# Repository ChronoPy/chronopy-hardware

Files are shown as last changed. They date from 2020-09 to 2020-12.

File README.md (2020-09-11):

# ChronoPy - Open Hardware, hacker freindly, wrist watch based on the OHS2020 badge
* [Hackaday.io project page](https://hackaday.io/project/168483-open-hardware-summit-2020-badge)
* [OHS 2020 website](http://2020.oshwa.org/)

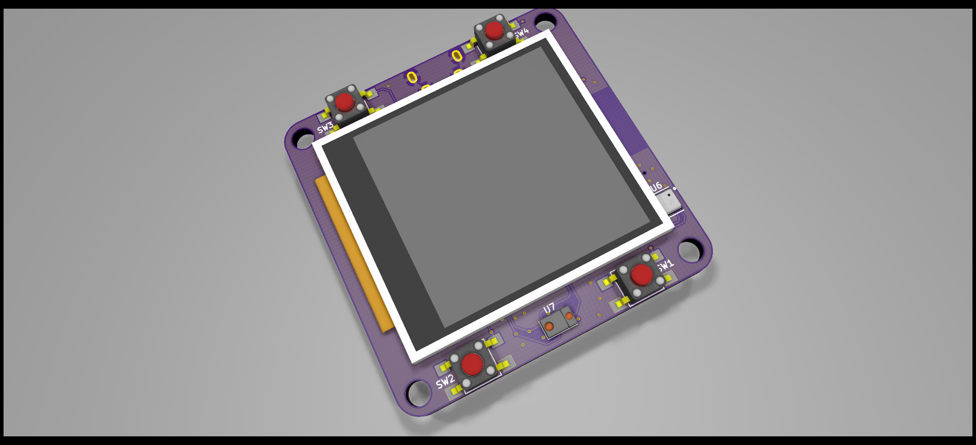
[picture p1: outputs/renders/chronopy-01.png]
Badge top

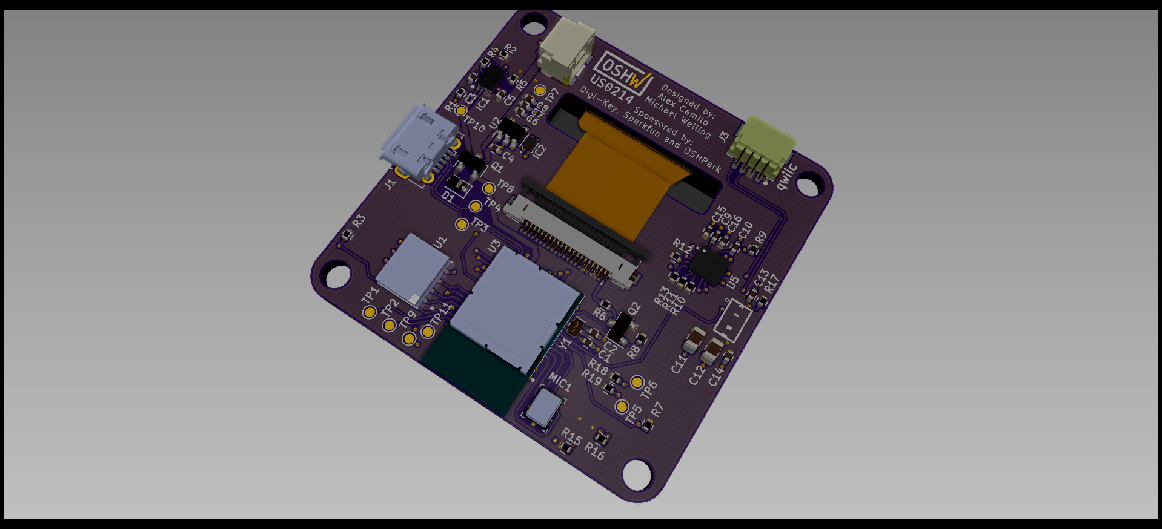
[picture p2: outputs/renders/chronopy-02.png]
Badge bot


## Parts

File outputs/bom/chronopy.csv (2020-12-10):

Reference | Quantity | Value | Footprint | Datasheet | Field4 | Field5 | Field6 | Field7 | Field8 | Description | Height | Manufacturer_Name | Manufacturer_Part_Number | Mouser Part Number | Mouser Price/Stock
C1 C2 | 2 | 18pF | ChronoPy-PCB:C_0402 | ~
C11 C12 | 2 | 10uF | ChronoPy-PCB:C_0805_2012Metric | ~
C18 | 1 | 220nF | ChronoPy-PCB:C_0402 | ~
C19 | 1 | 1uF | ChronoPy-PCB:C_0402 | ~
C15 C3 C4 C5 C6 C7 | 6 | 10uF | ChronoPy-PCB:C_0402 | ~
C10 C13 C14 C16 C17 C8 | 6 | 0.1uF | ChronoPy-PCB:C_0402 | ~
C9 | 1 | 10nF | ChronoPy-PCB:C_0402 | ~
D1 D2 | 2 | D | ChronoPy-PCB:D_SOD-323 | ~
IC1 | 1 | MCP73831T-2ACI_MC | ChronoPy-PCB:SON50P300X200X100-9N-D | https://componentsearchengine.com/Datasheets/1/MCP73831T-2ACI_MC.pdf |  |  |  |  |  | MICROCHIP - MCP73831T-2ACI/MC - BATTERY CHARGER, LI-ION/POL, 0.5A, DFN-8 | 1 | Microchip | MCP73831T-2ACI/MC | 579-MCP73831T-2ACIMC | https://www.mouser.com/Search/Refine.aspx?Keyword=579-MCP73831T-2ACIMC
IC2 | 1 | S-1000C32-I4T1U_S-1000C32-I4T1U | SNT-4A | http://datasheet.sii-ic.com/en/voltage_detector/S1000_E.pdf |  |  |  |  |  | ULTRA-SMALL PACKAGE HIGH-PRECISION VOLTAGE DETECTOR |  | SII Semiconductor | S-1000C32-I4T1U | 628-S-1000C32-I4T1U | http://www.mouser.com/Search/ProductDetail.aspx?qs=h6RIvS%252bzmlf9OAVfz2pa8w%3d%3d
J1 | 1 | USB_B_Micro | ChronoPy-PCB:USB_Micro-B_Molex-105017-0001 | ~
J2 | 1 | SM02B-SRSS-TB | ChronoPy-PCB:SM02B-SRSS-TB | 0.23 USD | JST | None | Good | SH Series 2 Position 1 mm Pitch Surface Mount Side Entry Shrouded Header | SM02B-SRSS-TB_LF__SN_
J3 | 1 | Conn_01x04_Shielded | ChronoPy-PCB:JST_SM04B-SRSS-TB(LF)(SN) | ~
J4 | 1 | Conn_01x13_MountingPin | ChronoPy-PCB:Hirose_FH26W-13S-0.3SHW_2Rows-13Pins-1MP_P0.60mm | ~
J5 | 1 | Conn_01x06_MountingPin | ChronoPy-PCB:Hirose_FH19C-6S-0.5SH_1x06-1MP_P0.50mm | ~
J6 | 1 | Conn_02x05_Odd_Even | Connector_PinHeader_1.27mm:PinHeader_2x05_P1.27mm_Horizontal | ~
J7 | 1 | TC2030-CTX | ChronoPy-PCB:TC2030-IDC-NL
M1 | 1 | Z43FC1B5640007L | ChronoPy-PCB:Z43FC1B5640007L | ~
MK1 | 1 | IM69D120 | Sensor_Audio:Infineon_PG-LLGA-5-1 | https://www.infineon.com/dgdl/Infineon-IM69D120-DS-v01_00-EN.pdf?fileId=5546d462602a9dc801607a0e41a01a2b
Q1 Q2 Q3 | 3 | AO3401A | ChronoPy-PCB:SOT-23 | http://www.aosmd.com/pdfs/datasheet/AO3401A.pdf
R14 | 1 | 800k | ChronoPy-PCB:R_0402 | ~
R17 | 1 | 22 | ChronoPy-PCB:R_0402 | ~
R20 | 1 | 2m | ChronoPy-PCB:R_0402 | ~
R21 R22 | 2 | 1k | ChronoPy-PCB:R_0402 | ~
R23 | 1 | 10m 1% | Resistor_SMD:R_0603_1608Metric | ~
R1 R18 R19 R4 | 4 | 10k | ChronoPy-PCB:R_0402 | ~
R10 R11 R12 R13 R15 R16 R2 R24 R3 R5 R7 R8 R9 | 13 | 100k | ChronoPy-PCB:R_0402 | ~
R6 | 1 | 33 | ChronoPy-PCB:R_0402 | ~
SW1 SW2 SW3 SW4 | 4 | SW_DIP_x01 | ChronoPy-PCB:SW_TL3340AF160QG | ~
TP10 TP12 TP3 TP4 TP5 TP6 TP7 TP8 TP9 | 9 | TestPoint | ChronoPy-PCB:Test_Point_Pad_d1.0mm | ~
U1 | 1 | W25Q32JVZPIQ | ChronoPy-PCB:SON127P600X500X80-9N | http://www.winbond.com/resource-files/w25q32jv%20revg%2003272018%20plus.pdf
U2 | 1 | AP2112K-3.3V | ChronoPy-PCB:SOT-23-5 | http://www.ti.com/lit/ds/symlink/lp2985.pdf
U3 | 1 | BMD-340-A-R | ChronoPy-PCB:RIGADO_BMD-340-A-R | U-Blox America | Module Rigado | Bluetooth Low Energy 5.0 Module | None | BMD-340-A-R | Unavailable
U4 | 1 | STC3115IJT | ChronoPy-PCB:CSP-10
U5 | 1 | LSM9DS1 | ChronoPy-PCB:PQFN24P43_350X300X102L35X23N | STMicroelectronics | TFLGA-24 STMicroelectronics | iNEMO inertial module: 3D accelerometer, 3D gyroscope, 3D magnetometer | None | LSM9DS1 | Unavailable
U6 | 1 | BME680 | ChronoPy-PCB:PSON80P300X300X100-8N | Bosch Sensortec | LGA-8 Bosch Tools | Integrated Environmental Unit | None | BME680 | Unavailable
U7 | 1 | APDS-9960 | ChronoPy-PCB:APDS-9960
Y1 | 1 | 32.768 | ChronoPy-PCB:Crystal_SMD_MicroCrystal_CM9V-T1A-2pin_1.6x1.0mm | https://www.mouser.com/datasheet/2/530/CM9V-T1A-1023054.pdf

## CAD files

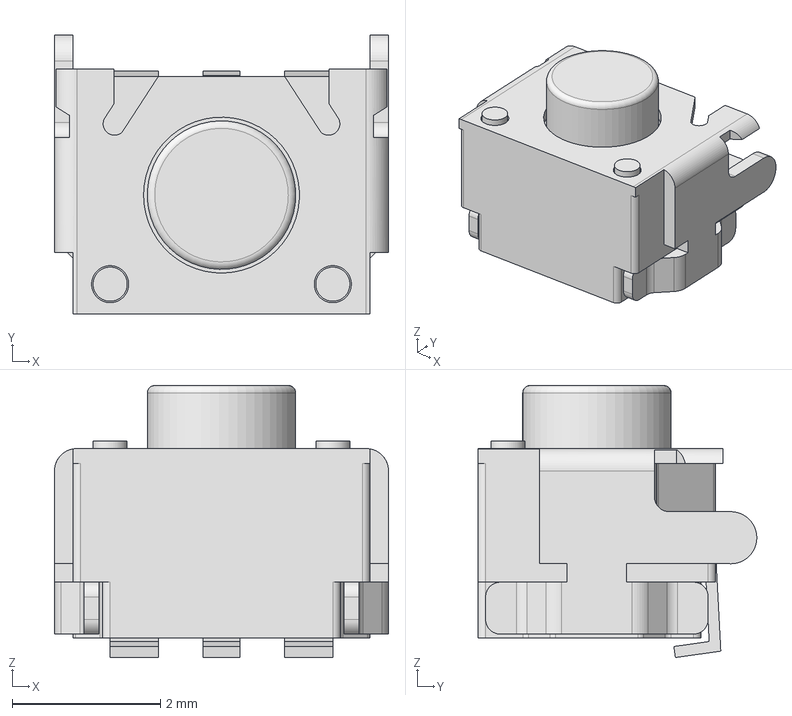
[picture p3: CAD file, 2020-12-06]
3d_part_models/TL3340AF160QG.stp
4.50 x 3.75 x 3.67 mm

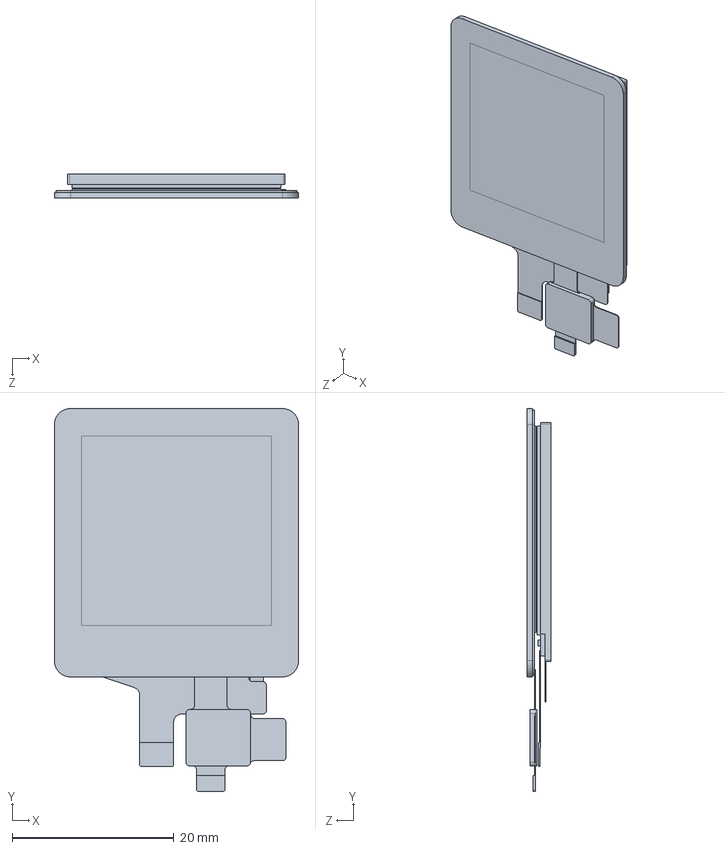
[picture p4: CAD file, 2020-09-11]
assets/CAD/TF-LCM13018A-C-S1_OL_5.step
30.2 x 47.3 x 3.00 mm

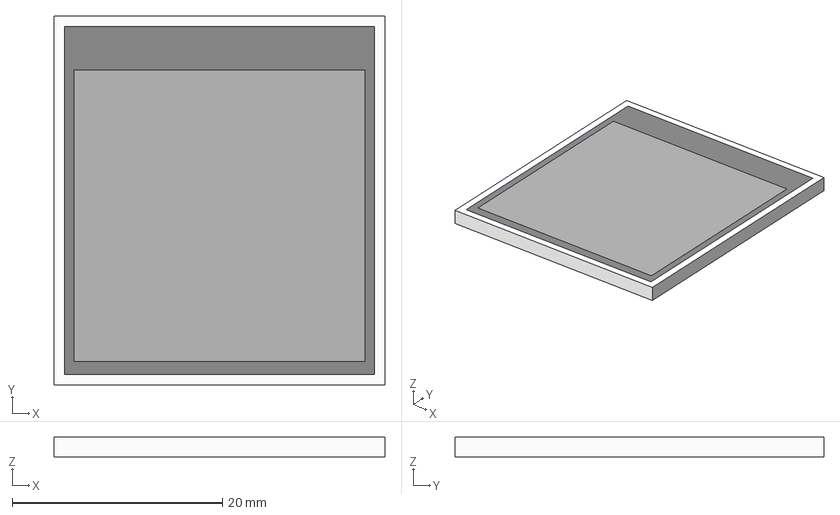
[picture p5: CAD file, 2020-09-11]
assets/CAD/TFT_LCD.step
31.5 x 35.1 x 1.90 mm
TFT_1.54IN_240X240_22PIN
TFT_1.54IN_240X240_22PIN001
TFT_1.54IN_240X240_22PIN002

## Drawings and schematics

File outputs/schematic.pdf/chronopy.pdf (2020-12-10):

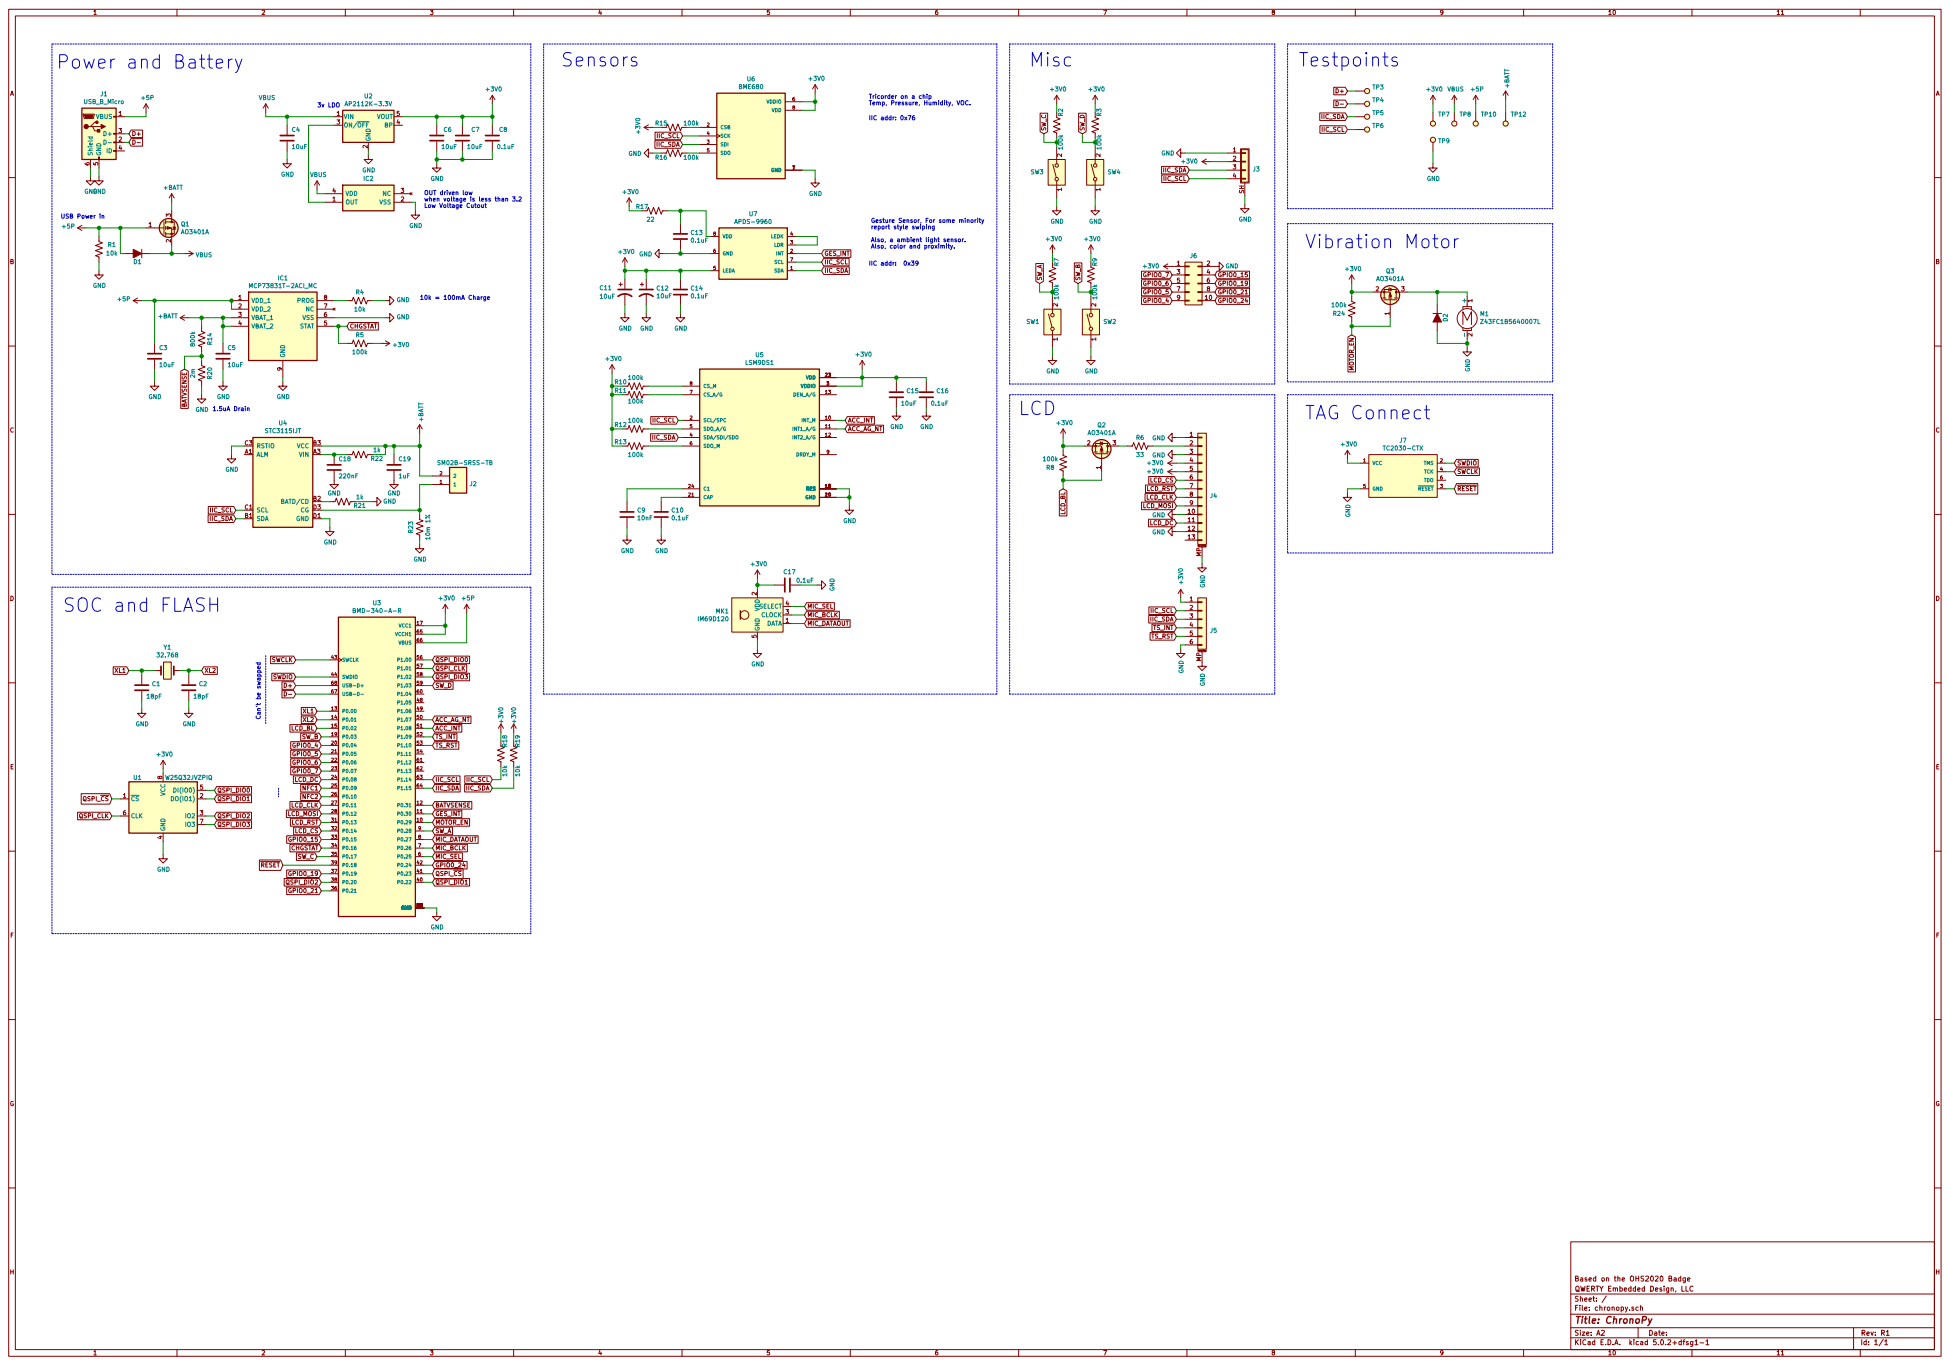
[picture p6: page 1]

J1 USB_B_Micro
Low Voltage Cutout +5P GNDGND

2 ON/OFF 3 BP 4 VOUT 5 U2 AP2112K-3.3V GND
3v LDO

Tricorder on a chip
Temp, Pressure, Humidity, VOC.

OUT driven low
when voltage is less than 3.2

Gesture Sensor, For some minority
report style swiping
Also, a ambient light sensor.
Also, color and proximity.

Based on the OHS2020 Badge
File: chronopy.sch Sheet: / QWERTY Embedded Design, LLC

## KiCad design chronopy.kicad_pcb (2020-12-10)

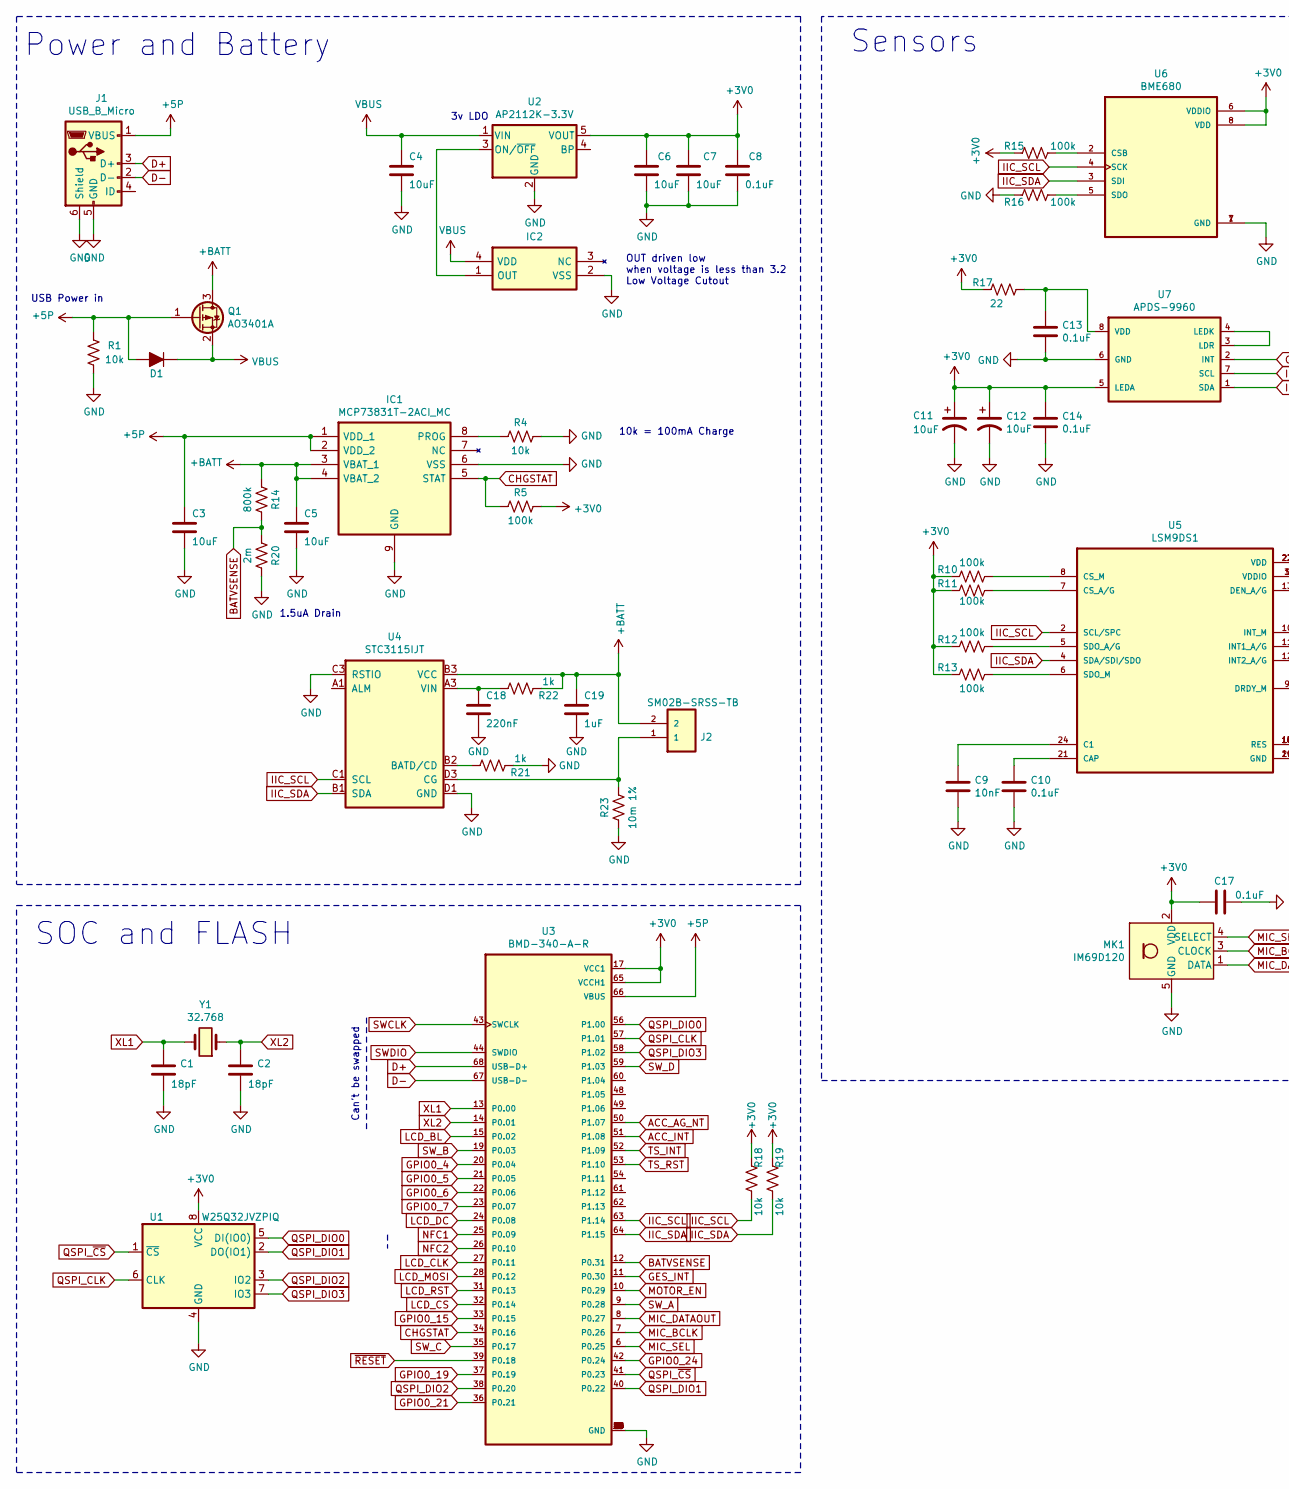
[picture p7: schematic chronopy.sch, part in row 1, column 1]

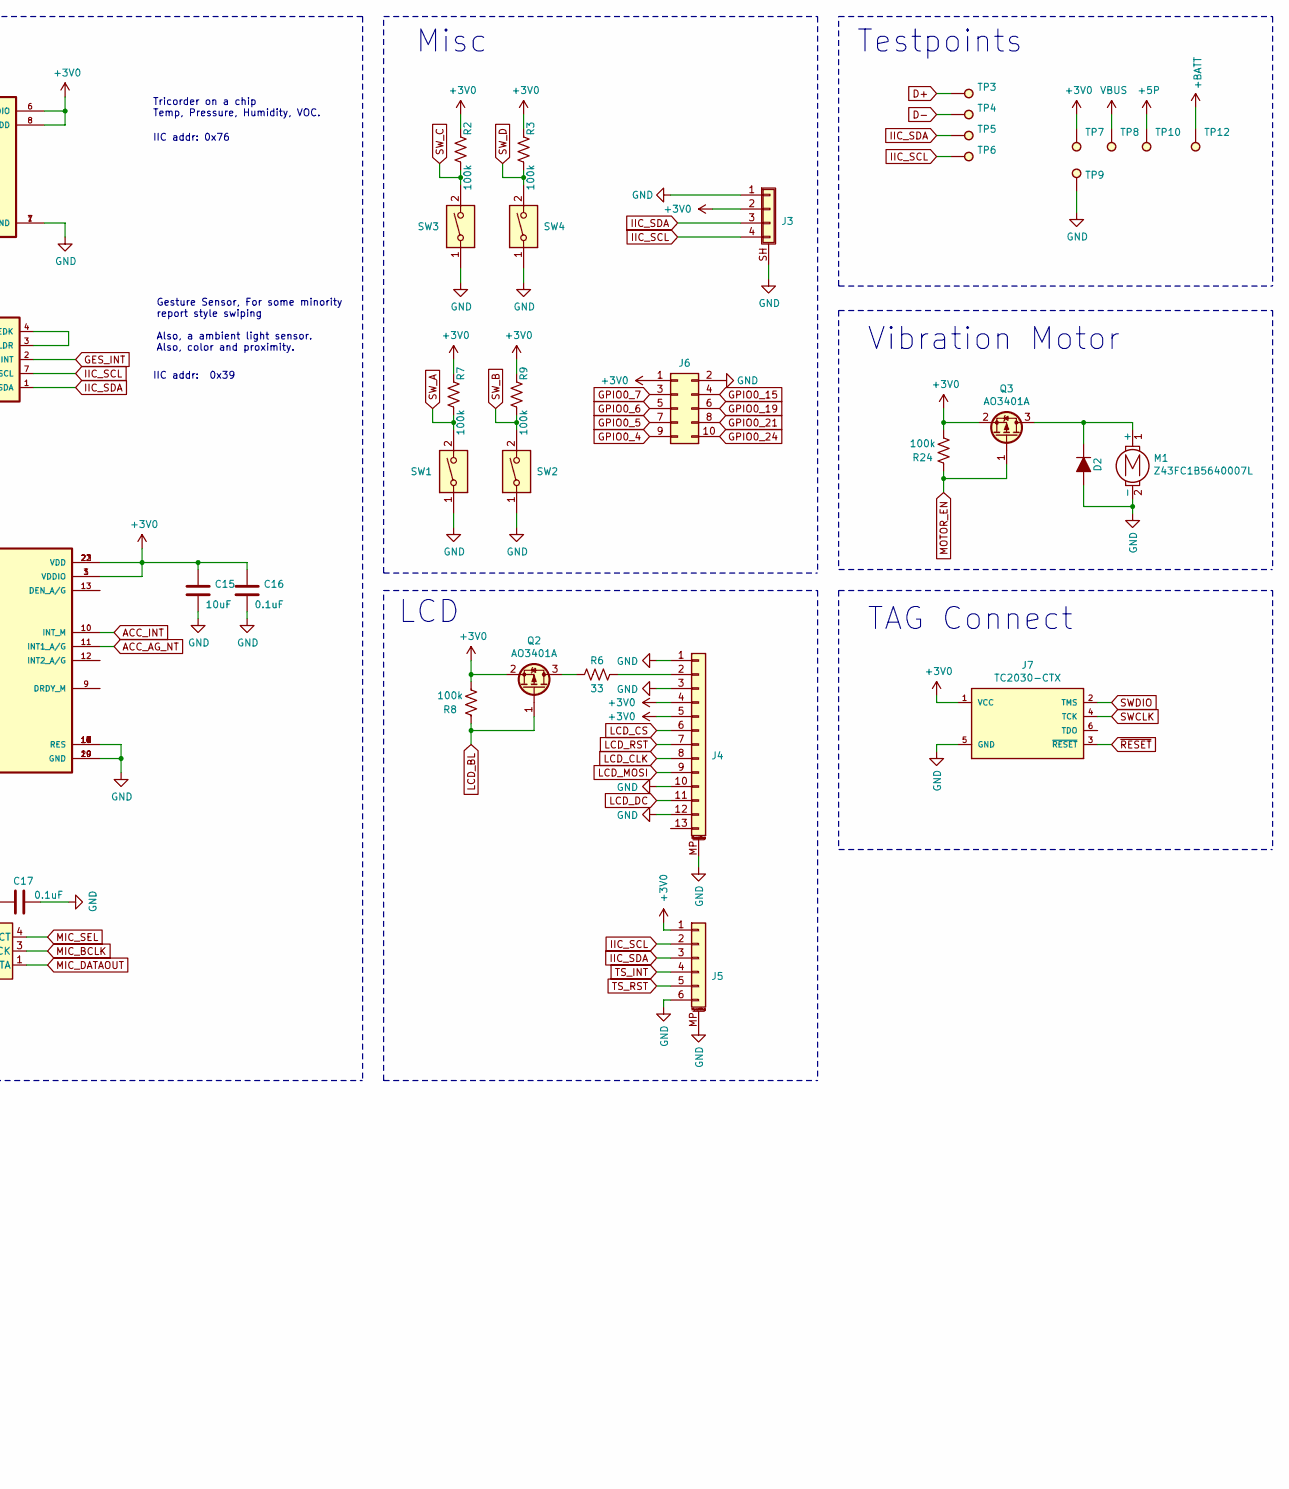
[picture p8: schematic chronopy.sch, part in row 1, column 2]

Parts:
C1, C2: 18pF; C_0402
C3, C4, C5, C6, C7, C15: 10uF; C_0402
C8, C10, C13, C14, C16, C17: 0.1uF; C_0402
C9: 10nF; C_0402
C11, C12: 10uF; C_0805_2012Metric
C18: 220nF; C_0402
C19: 1uF; C_0402
D1, D2: D; D_SOD-323
IC1: MCP73831T-2ACI_MC; SON50P300X200X100-9N-D; Mouser Part Number 579-MCP73831T-2ACIMC
IC2: S-1000C32-I4T1U_S-1000C32-I4T1U; SNT-4A; Manufacturer_Part_Number S-1000C32-I4T1U; Mouser Part Number 628-S-1000C32-I4T1U
J1: USB_B_Micro; USB_Micro-B_Molex-105017-0001
J2: SM02B-SRSS-TB
J3: Conn_01x04_Shielded; JST_SM04B-SRSS-TB(LF)(SN)
J4: Conn_01x13_MountingPin; Hirose_FH26W-13S-0.3SHW_2Rows-13Pins-1MP_P0.60mm
J5: Conn_01x06_MountingPin; Hirose_FH19C-6S-0.5SH_1x06-1MP_P0.50mm
J6: Conn_02x05_Odd_Even; PinHeader_2x05_P1.27mm_Horizontal
J7: TC2030-CTX; TC2030-IDC-NL
M1: Z43FC1B5640007L
MK1: IM69D120; Infineon_PG-LLGA-5-1
Q1, Q2, Q3: AO3401A; SOT-23
R1, R4, R18, R19: 10k; R_0402
R2, R3, R5, R7, R8, R9, R10, R11, R12, R13, R15, R16, R24: 100k; R_0402
R6: 33; R_0402
R14: 800k; R_0402
R17: 22; R_0402
R20: 2m; R_0402
R21, R22: 1k; R_0402
R23: 10m 1%; R_0603_1608Metric
SW1, SW2, SW3, SW4: SW_DIP_x01; SW_TL3340AF160QG
TP3, TP4, TP5, TP6, TP7, TP8, TP9, TP10, TP12: TestPoint; Test_Point_Pad_d1.0mm
U1: W25Q32JVZPIQ; SON127P600X500X80-9N
U2: AP2112K-3.3V; SOT-23-5
U3: BMD-340-A-R; RIGADO_BMD-340-A-R
U4: STC3115IJT; CSP-10
U5: LSM9DS1; PQFN24P43_350X300X102L35X23N
U6: BME680; PSON80P300X300X100-8N
U7: APDS-9960
Y1: 32.768; Crystal_SMD_MicroCrystal_CM9V-T1A-2pin_1.6x1.0mm

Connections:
+3V0: C6.1, C7.1, C8.1, C11.1, C12.1, C14.1, C15.1, C16.1, C17.1, J3.2, J4.4, J4.5, J5.1, J6.1, J7.1 (VCC), MK1.2 (VDD), Q2.2 (S), Q3.2 (S), R2.2, R3.2, R5.1, R7.2, R8.1, R9.2, R10.2, R11.2, R12.2, R13.2, R15.2, R17.2, R18.2, R19.2, R24.1, TP7.1, U1.8 (VCC), U2.5 (VOUT), U3.17 (VCC1), U3.65 (VCCH1), U5.1 (VDDIO), U5.3 (VDDIO), U5.22 (VDD), U5.23 (VDD), U6.6 (VDDIO), U6.8 (VDD), U7.5 (LEDA)
+5P: C3.1, D1.2 (A), IC1.1 (VDD_1), IC1.2 (VDD_2), J1.1 (VBUS), Q1.1 (G), R1.2, TP10.1, U3.66 (VBUS)
+BATT: C5.1, C19.1, IC1.3 (VBAT_1), IC1.4 (VBAT_2), J2.2, Q1.3 (D), R14.2, R22.2, TP12.1, U4.B3 (VCC)
ACC_AG_NT: U3.50 (P1.07), U5.11 (INT1_A/G)
ACC_INT: U3.51 (P1.08), U5.10 (INT_M)
BATVSENSE: R14.1, R20.2, U3.12 (P0.31)
CHGSTAT: IC1.5 (STAT), R5.2, U3.34 (P0.16)
D+: J1.3 (D+), TP3.1, U3.68 (USB-D+)
D-: J1.2 (D-), TP4.1, U3.67 (USB-D-)
GES_INT: U3.11 (P0.30), U7.2 (INT)
GND: C1.2, C2.2, C3.2, C4.2, C5.2, C6.2, C7.2, C8.2, C9.1, C10.1, C11.2, C12.2, C13.2, C14.2, C15.2, C16.2, C17.2, C18.2, C19.2, D2.2 (A), IC1.6 (VSS), IC1.9 (GND), IC2.2 (VSS), J1.5 (GND), J1.6 (Shield), J3.1, J3.SH (Shield), J4.1, J4.3, J4.10, J4.12, J4.MP (MountPin), J5.6, J5.MP (MountPin), J6.2, J7.5 (GND), M1.2 (-), MK1.5 (GND), R1.1, R4.1, R16.2, R20.1, R21.2, R23.1, SW1.1, SW2.1, SW3.1, SW4.1, TP9.1, U1.4 (GND), U2.2 (GND), U3.1 (GND), U3.2 (GND), U3.3 (GND), U3.4 (GND), U3.5 (GND), U3.16 (GND), U3.18 (GND), U3.29 (GND), U3.30 (GND), U3.45 (GND), U3.46 (GND), U3.47 (GND), U3.55 (GND), U4.C3 (RSTIO), U4.D1 (GND), U5.14 (RES), U5.15 (RES), U5.16 (RES), U5.17 (RES), U5.18 (RES), U5.19 (GND), U5.20 (GND), U6.1 (GND), U6.7 (GND), U7.6 (GND)
GPIO0_4: J6.9, U3.20 (P0.04)
GPIO0_5: J6.7, U3.21 (P0.05)
GPIO0_6: J6.5, U3.22 (P0.06)
GPIO0_7: J6.3, U3.23 (P0.07)
GPIO0_15: J6.4, U3.33 (P0.15)
GPIO0_19: J6.6, U3.37 (P0.19)
GPIO0_21: J6.8, U3.36 (P0.21)
GPIO0_24: J6.10, U3.42 (P0.24)
IIC_SCL: J3.4, J5.2, R18.1, TP6.1, U3.63 (P1.14), U4.C1 (SCL), U5.2 (SCL/SPC), U6.4 (SCK), U7.7 (SCL)
IIC_SDA: J3.3, J5.3, R19.1, TP5.1, U3.64 (P1.15), U4.B1 (SDA), U5.4 (SDA/SDI/SDO), U6.3 (SDI), U7.1 (SDA)
LCD_BL: Q2.1 (G), R8.2, U3.15 (P0.02)
LCD_CLK: J4.8, U3.27 (P0.11)
LCD_CS: J4.6, U3.32 (P0.14)
LCD_DC: J4.11, U3.24 (P0.08)
LCD_MOSI: J4.9, U3.28 (P0.12)
LCD_RST: J4.7, U3.31 (P0.13)
MIC_BCLK: MK1.3 (CLOCK), U3.7 (P0.26)
MIC_DATAOUT: MK1.1 (DATA), U3.8 (P0.27)
MIC_SEL: MK1.4 (SELECT), U3.6 (P0.25)
MOTOR_EN: Q3.1 (G), R24.2, U3.10 (P0.29)
NFC1: U3.25 (P0.09)
NFC2: U3.26 (P0.10)
unnamed: C9.2, U5.24 (C1)
unnamed: C10.2, U5.21 (CAP)
unnamed: C13.1, R17.1, U7.8 (VDD)
unnamed: C18.1, R22.1, U4.A3 (VIN)
unnamed: D2.1 (K), M1.1 (+), Q3.3 (D)
unnamed: IC1.8 (PROG), R4.2
unnamed: IC2.1 (OUT), U2.3 (ON/~OFF~)
unnamed: J2.1, R23.2, U4.D3 (CG)
unnamed: J4.2, R6.1
unnamed: Q2.3 (D), R6.2
unnamed: R10.1, U5.8 (CS_M)
unnamed: R11.1, U5.7 (CS_A/G)
unnamed: R12.1, U5.5 (SDO_A/G)
unnamed: R13.1, U5.6 (SDO_M)
unnamed: R15.1, U6.2 (CSB)
unnamed: R16.1, U6.5 (SDO)
unnamed: R21.1, U4.B2 (BATD/CD)
unnamed: U7.3 (LDR), U7.4 (LEDK)
QSPI_CLK: U1.6 (CLK), U3.57 (P1.01)
QSPI_DIO0: U1.5 (DI(IO0)), U3.56 (P1.00)
QSPI_DIO1: U1.2 (DO(IO1)), U3.40 (P0.22)
QSPI_DIO2: U1.3 (IO2), U3.38 (P0.20)
QSPI_DIO3: U1.7 (IO3), U3.58 (P1.02)
QSPI_~CS: U1.1 (~CS), U3.41 (P0.23)
SWCLK: J7.4 (TCK), U3.43 (SWCLK)
SWDIO: J7.2 (TMS), U3.44 (SWDIO)
SW_A: R7.1, SW1.2, U3.9 (P0.28)
SW_B: R9.1, SW2.2, U3.19 (P0.03)
SW_C: R2.1, SW3.2, U3.35 (P0.17)
SW_D: R3.1, SW4.2, U3.59 (P1.03)
TS_INT: J5.4, U3.52 (P1.09)
TS_RST: J5.5, U3.53 (P1.10)
VBUS: C4.1, D1.1 (K), IC2.4 (VDD), Q1.2 (S), TP8.1, U2.1 (VIN)
XL1: C1.1, U3.13 (P0.00), Y1.2
XL2: C2.1, U3.14 (P0.01), Y1.1
~RESET: J7.3 (~RESET), U3.39 (P0.18)

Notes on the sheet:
3v LDO
OUT driven low when voltage is less than 3.2 Low Voltage Cutout
USB Power in
10k = 100mA Charge
Power and Battery
LCD
SOC and FLASH
Sensors
Can't be swapped
Testpoints
Gesture Sensor, For some minority report style swiping Also, a ambient light sensor. Also, color and proximity.
Tricorder on a chip Temp, Pressure, Humidity, VOC.
IIC addr: 0x76
IIC addr: 0x39
1.5uA Drain
Misc
Vibration Motor
TAG Connect

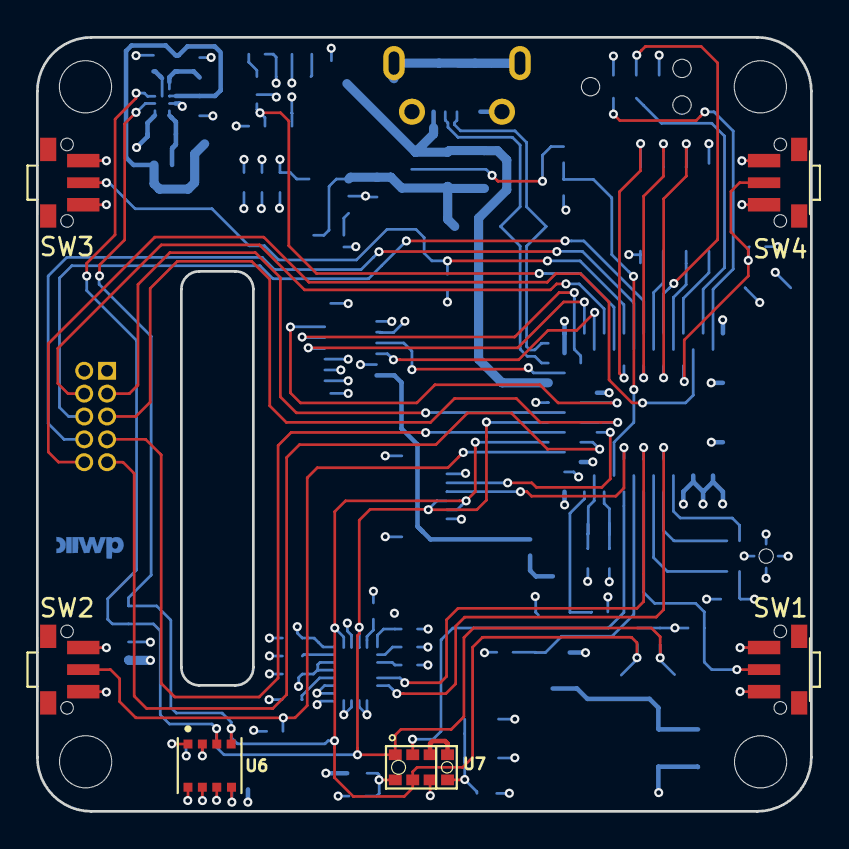
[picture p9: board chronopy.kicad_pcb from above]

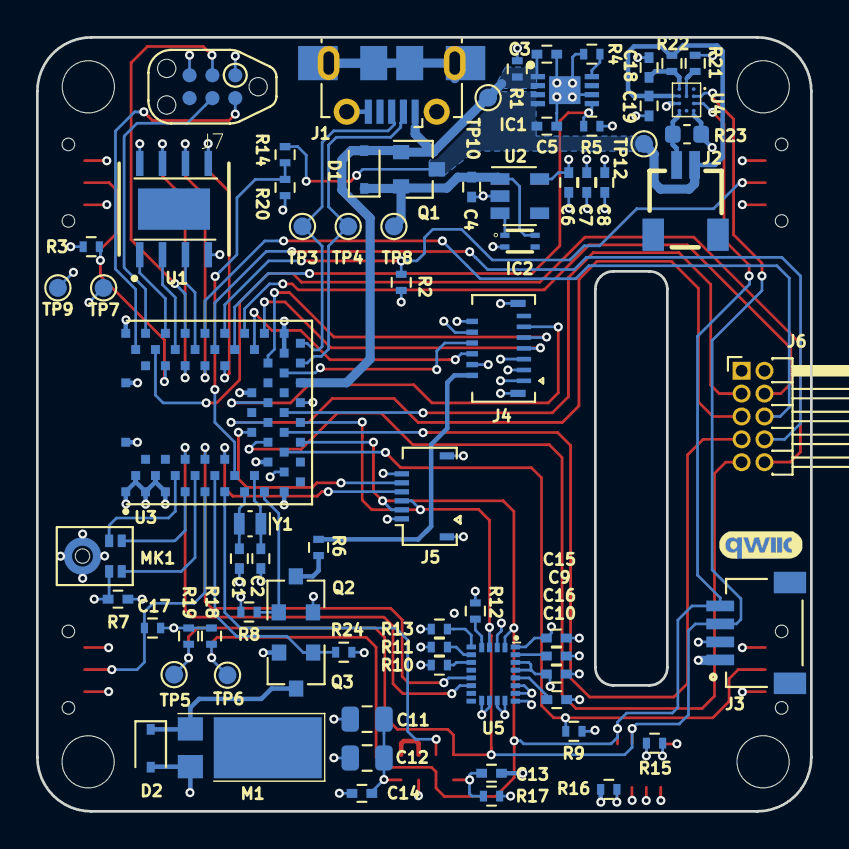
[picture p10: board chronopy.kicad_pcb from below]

Board: 4 copper layers, 43.0 x 43.0 mm, 81 parts (75 on the bottom side), 67 nets.

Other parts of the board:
Ref**: Val**; Qwiic lozenge curves-shenzen

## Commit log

2020-09-11 Rename everything to ChronoPY and clean up a bit
    [badge-B.Cu.gbr, badge-B.Mask.gbr, badge-B.Paste.gbr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]
2020-09-11 Sync plots in new directory
    [chronopy-B.Cu.gbr, chronopy-B.Mask.gbr, chronopy-B.Paste.gbr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]
2020-09-11 Remove stale Gerbers
    [badge-B.Cu.gbr, badge-B.Mask.gbr, badge-B.Paste.gbr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]
2020-09-11 Remove stale schematic pdf
2020-09-11 Move various assets into a separate directory
    [TFT_LCD.step]
2020-09-11 Add datasheets for new 1.3" SPI LCD and connectors
2020-09-11 Add vendor step model for the new LCD
    [TF-LCM13018A-C-S1_OL_5.step]
2020-09-11 Tidy up schematic and add TODO list
    [chronopy.sch]
2020-09-11 Update footprint references in schematic and sync
    [chronopy.kicad_pcb, chronopy.sch]
2020-09-11 Update hole size of mic in library and PCB
    [chronopy.kicad_pcb]
2020-09-21 Some updates from the weekend
    [chronopy.kicad_pcb, chronopy.sch]
2020-09-28 Added Fuel Gauge IC
    [chronopy.sch]
2020-10-31 Clean up schematic changes for fuel gauge
    Cleans schematic a bit and start the layout for the fuel gauge.
    [chronopy.kicad_pcb, chronopy.sch]
2020-12-04 Adds new fuel gauge and vibration motor
    [chronopy.kicad_pcb, chronopy.sch]
2020-12-06 Switch to side shooter buttons and add Tag connect
    [TL3340AF160QG.stp, chronopy.kicad_pcb, chronopy.sch]
2020-12-06 Tweak fuel gauge routing a bit
    [chronopy.kicad_pcb]
2020-12-10 Generate outputs for fab
    [chronopy-B.Cu.gbr, chronopy-B.Mask.gbr, chronopy-B.Paste.gbr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]
